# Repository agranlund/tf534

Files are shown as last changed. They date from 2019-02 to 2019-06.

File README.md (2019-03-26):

# Terriblefire TF534 

The TF534 doesnt work under 25Mhz. The firmware is designed to work between 25Mhz and 50Mhz. Its optimized for 50Mhz & 33Mhz.

Where this BOM differs from the schematic use the BOM value. 

| | | | | |
|---|---|---|---|---|
| "Part" | "Value" | "Device" | "Package" | "Description" |
| "C1" | "10uF" | "CAP_1206_X7R" | "1206" | "Ceramic Capacitors" |
| "C2" | "10uF" | "CAP_1206_X7R" | "1206" | "Ceramic Capacitors" |
| "C3" | "10uF" | "CAP_1206_X7R" | "1206" | "Ceramic Capacitors" |
| "C4" | "10uF" | "CAP_1206_X7R" | "1206" | "Ceramic Capacitors" |
| "C5" | "10uF" | "CAP_1206_X7R" | "1206" | "Ceramic Capacitors" |
| "C6" | "10uF" | "CAP_1206_X7R" | "1206" | "Ceramic Capacitors" |
| "C7" | "10uF" | "CAP_1206_X7R" | "1206" | "Ceramic Capacitors" |
| "C8" | "10uF" | "CAP_1206_X7R" | "1206" | "Ceramic Capacitors" |
| "C9" | "10uF" | "CAP_1206_X7R" | "1206" | "Ceramic Capacitors" |
| "C10" | "10uF" | "CAP_1206_X7R" | "1206" | "Ceramic Capacitors" |
| "C11" | "10uF" | "CAP_1206_X7R" | "1206" | "Ceramic Capacitors" |
| "C12" | "10uF" | "CAP_1206_X7R" | "1206" | "Ceramic Capacitors" |
| "C13" | "10uF" | "CAP_1206_X7R" | "1206" | "Ceramic Capacitors" |
| "C14" | "10uF" | "CAP_1206_X7R" | "1206" | "Ceramic Capacitors" |
| "C15" | "10uF" | "CAP_1206_X7R" | "1206" | "Ceramic Capacitors" |
| "C16" | "0.1uF" | "CAP_0603_X7R" | "0603" | "CAP-00810" |
| "C17" | "0.1uF" | "CAP_0603_X7R" | "0603" | "CAP-00810" |
| "C18" | "0.1uF" | "CAP_1206_X7R" | "1206" | "Ceramic Capacitors" |
| "C19" | "0.1uF" | "CAP_0603_X7R" | "0603" | |
| "C20" | "0.1uF" | "CAP_0603_X7R" | "0603" | "CAP-00810" |
| "C21" | "0.1uF" | "CAP_0603_X7R" | "0603" | |
| "C22" | "0.1uF" | "CAP_0603_X7R" | "0603" | |
| "C23" | "0.1uF" | "CAP_0603_X7R" | "0603" | |
| "C24" | "0.1uF" | "CAP_0603_X7R" | "0603" | |
| "C25" | "0.1uF" | "CAP_0603_X7R" | "0603" | |
| "C26" | "0.1uF" | "CAP_0603_X7R" | "0603" | |
| "C27" | "0.1uF" | "CAP_0603_X7R" | "0603" | |
| "C28" | "0.1uF" | "CAP_0603_X7R" | "0603" | |
| "C29" | "0.1uF" | "CAP_0603_X7R" | "0603" | |
| "C30" | "0.1uF" | "CAP_0603_X7R" | "0603" | |
| "C31" | "10uF" | "CAP_1206_X7R" | "1206" | "Ceramic Capacitors" |
| "IC1" | "MC68030RC" | "68030" | "MPGA128" | "MOTOROLA" |
| "IC2" | "MC68881FN-SOC" | "68882" | "PLCC68-S" | "unknown" |
| "IC3" | "LM1117-3.3" | "V_REG_LM1117SOT223" | "SOT223" | "Voltage Regulator LM1117" |
| "IC4" | "74LVC1G17DBV" | "74LVC1G17DBV" | "SOT23-5" | "Single Schmitt-Trigger Buffer" |
| "IC5" | "74LVC1G17DBV" | "74LVC1G17DBV" | "SOT23-5" | "Single Schmitt-Trigger Buffer" |
| "IC6" | "AS6C800855ZIN" | "AS6C800855ZIN" | "TSOP44-II" | |
| "IC7" | "AS6C800855ZIN" | "AS6C800855ZIN" | "TSOP44-II" | |
| "IC8" | "AS6C800855ZIN" | "AS6C800855ZIN" | "TSOP44-II" | |
| "IC9" | "AS6C800855ZIN" | "AS6C800855ZIN" | "TSOP44-II" | |
| "IC10" | "74AC16245" | "74AC16245" | "SSOP48DL" | "16-bit BUS TRANSCEIVER, 3-state" |
| "IDECONNECTOR" | "87758-4416" | "87758-4416" | "87758-4416" | "44 Pin - 2mm Dual Row  HDR" |
| "INT2" | "PINHD-1X1" | "1X01" | "PIN HEADER" | |
| "JP1" | "CLOCKSEL" | "JUMPER-3PTH" | "1X03" | |
| "JP2" | "Z2ROM" | "JUMPER-2PTH" | "1X02" | "Jumper" |
| "JP3" | "MMUDIS" | "JUMPER-2PTH" | "1X02" | "Jumper" |
| "JP4" | "ROMEN" | "JUMPER-2PTH" | "1X02" | "Jumper" |
| "JP5" | "CDIS" | "JUMPER-2PTH" | "1X02" | "Jumper" |
| "JTAG" | "JTAG" | "HEADER-1X6" | "0.1 header x 6" | "PIN HEADER" |
| "OSCCPU" | "CPUMHZ" | "OSCILLATOR" | "OSC_7X5MM" | "Oscillators" |
| "PWR1" | "EXT5V" | "JUMPER-2PTH" | "1X02" | "Jumper" |
| "R1" | "2K2" | "0.05OHM-1/5W-1%(0603)" | "0603" | "RES-12535" |
| "R2" | "2K2" | "0.05OHM-1/5W-1%(0603)" | "0603" | "RES-12535" |
| "R3" | "47K" | "RESISTOR1206" | "1206" | "Resistors" |
| "RN1" | "CAY16-222J4LF" | "CAY16-222J4LF" | "RESCAXE80P320X160-8N" | "Res Thick Film Array 2K2 Ohm" |
| "RN2" | "CAY16-222J4LF" | "CAY16-222J4LF" | "RESCAXE80P320X160-8N" | "Res Thick Film Array 2K2 Ohm" |
| "RN3" | "CAY16-222J4LF" | "CAY16-222J4LF" | "RESCAXE80P320X160-8N" | "Res Thick Film Array 2K2 Ohm" |
| "SPIPORT" | "SPI PORT" | "PINHD-2X6" | "2X06" | "PIN HEADER" |
| "SPI_INT" | "NONE" | "PINHD-1X1" | "1X01" | "PIN HEADER" |
| "U1" | "3.3V SPI Flash"  | "SST26VF016B" | "SO08" | "32M Serial Flash Memory" |
| "X1" | "MC68000" | "MC68000P" | "DIL64" | "68xxx PROCESSOR" |
| "XC9572XL(BUS)"  | "XC9572XL-VQ64" | "XC9572XL-VQ64" | "VQ64" | |
| "XC95144XL(RAM)" | "XC95144XL-TQ100" | "XC95144XL-TQ100" | "TQFP100" | |

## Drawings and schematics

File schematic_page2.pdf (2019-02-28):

# 19 D0

# 36 GND

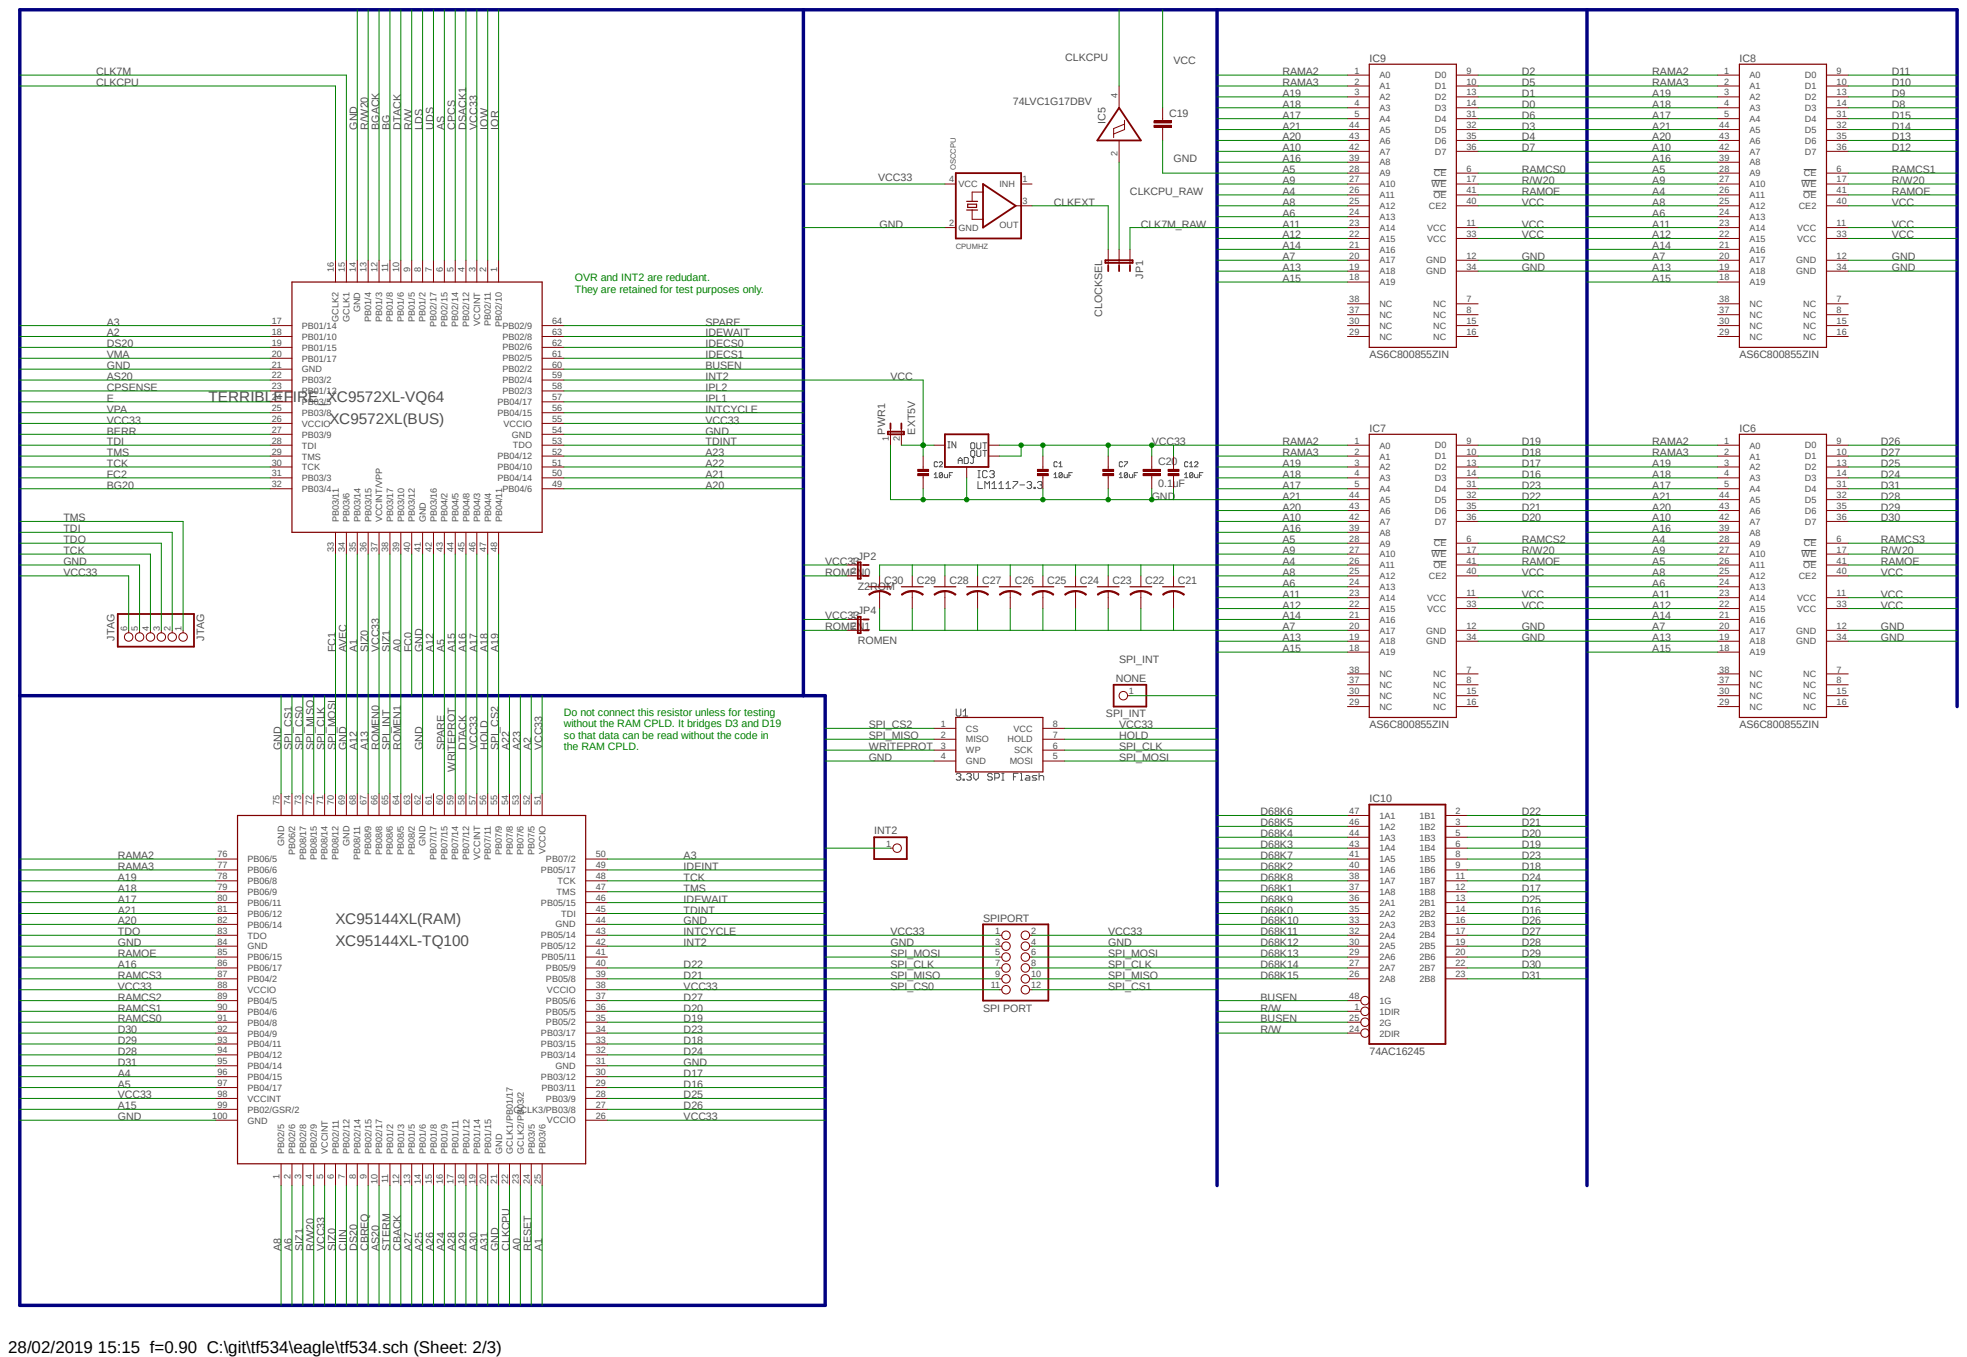
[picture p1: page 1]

A18 | | A18 | 14 D4 D8
A17 | D6 | A17 | 31 D5
A21 | | A21 44 A6 | 32 D6
A20 | | A20 43 A7 | 35 D7
A10 | | A10 42 A8

A6 | VCC | A6 | 40 VCC 11 VCC VCC
A8 | VCC | A8 | VCC

7 PB03/2 22 PB03/3 31 PB03/4 32 PB03/5 24 PB03/6 34 PB03/8 25 PB03/9 27 PB03/10 39 PB03/11 33 PB03/12 40 PB03/14 35 PB03/15 36 PB03/16 42 PB03/17 38 PB04/2 43 PB04/3 46 PB04/4 47 PB04/5 44 PB04/6 49 PB04/8 45 PB04/10 51 PB04/11 48 PB04/12 52 PB04/14 50 PB04/15 56 PB04/17 57 TCK 30 TDI 28 TDO 53 TMS 29 VCCINT

3 VCCINT/VPP 37 VCCIO 55 VCCIO 26 XC9572XL(BUS)

A15 | | A15 | 34 NC 7 NC 8 NC 15 NC
A13 | GND | A13 | GND

OVR and INT2 are redudant.
They are retained for test purposes only.

IDECS1 | AS6C800855ZIN IC7 | AS6C800855ZIN

GND | BUSEN
AS20 | INT2
CPSENSE | IPL2 | JP2 1

A11 | VCC | A11 A8 | 40 VCC 11 VCC VCC

VCC | | 33 VCC

GND | | 12 GND GND

Do not connect this resistor unless for testing
without the RAM CPLD. It bridges D3 and D19
so that data can be read without the code in
the RAM CPLD.

6 VCCIO 26 GND 31 PB05/2 35 PB05/5 36 PB05/6 37 PB05/8 39 PB05/9 40 PB05/11 41 PB05/12 42 PB05/14 43 PB05/15 46 PB05/17 49 VCCIO 38 GND 44 PB07/2 PB07/5 50 52 PB07/6 53 PB08/2 63 PB07/8 54 PB07/9 55 PB07/11 56 PB07/12 58 PB07/14 59 PB07/15 60 PB07/17 61 VCCIO 51 VCCINT 57 PB08/5 64 PB08/6 65 PB08/8 66 PB08/9 67 PB08/11 68 PB08/12 70 PB08/14 71 PB08/15 72 PB08/17 73 GND 69 PB06/2 74 PB06/5 76 PB06/6 77 PB06/8 78 PB06/9 79 PB06/11 80 PB06/12 81 PB06/14 82 PB06/15 85 PB06/17 86 GND 75 GND 84 PB04/2 87 PB04/5 89 PB04/6 90 PB04/8 91 PB04/9 92 PB04/11 93 PB04/12 94 PB04/14 95 PB04/15 96 PB04/17 97 VCCIO 88 GND 100 VCCINT 98 PB02/GSR/2 99

VCC33 | VCC33
RAMCS2 | D27
RAMCS0 | D19
D30 | D23
D29 | D18
D28 | D24
D31 | GND
A5 | D16
VCC33 | D25

28/02/2019 15:15 f=0.90 C:\git\tf534\eagle\tf534.sch (Sheet: 2/3)

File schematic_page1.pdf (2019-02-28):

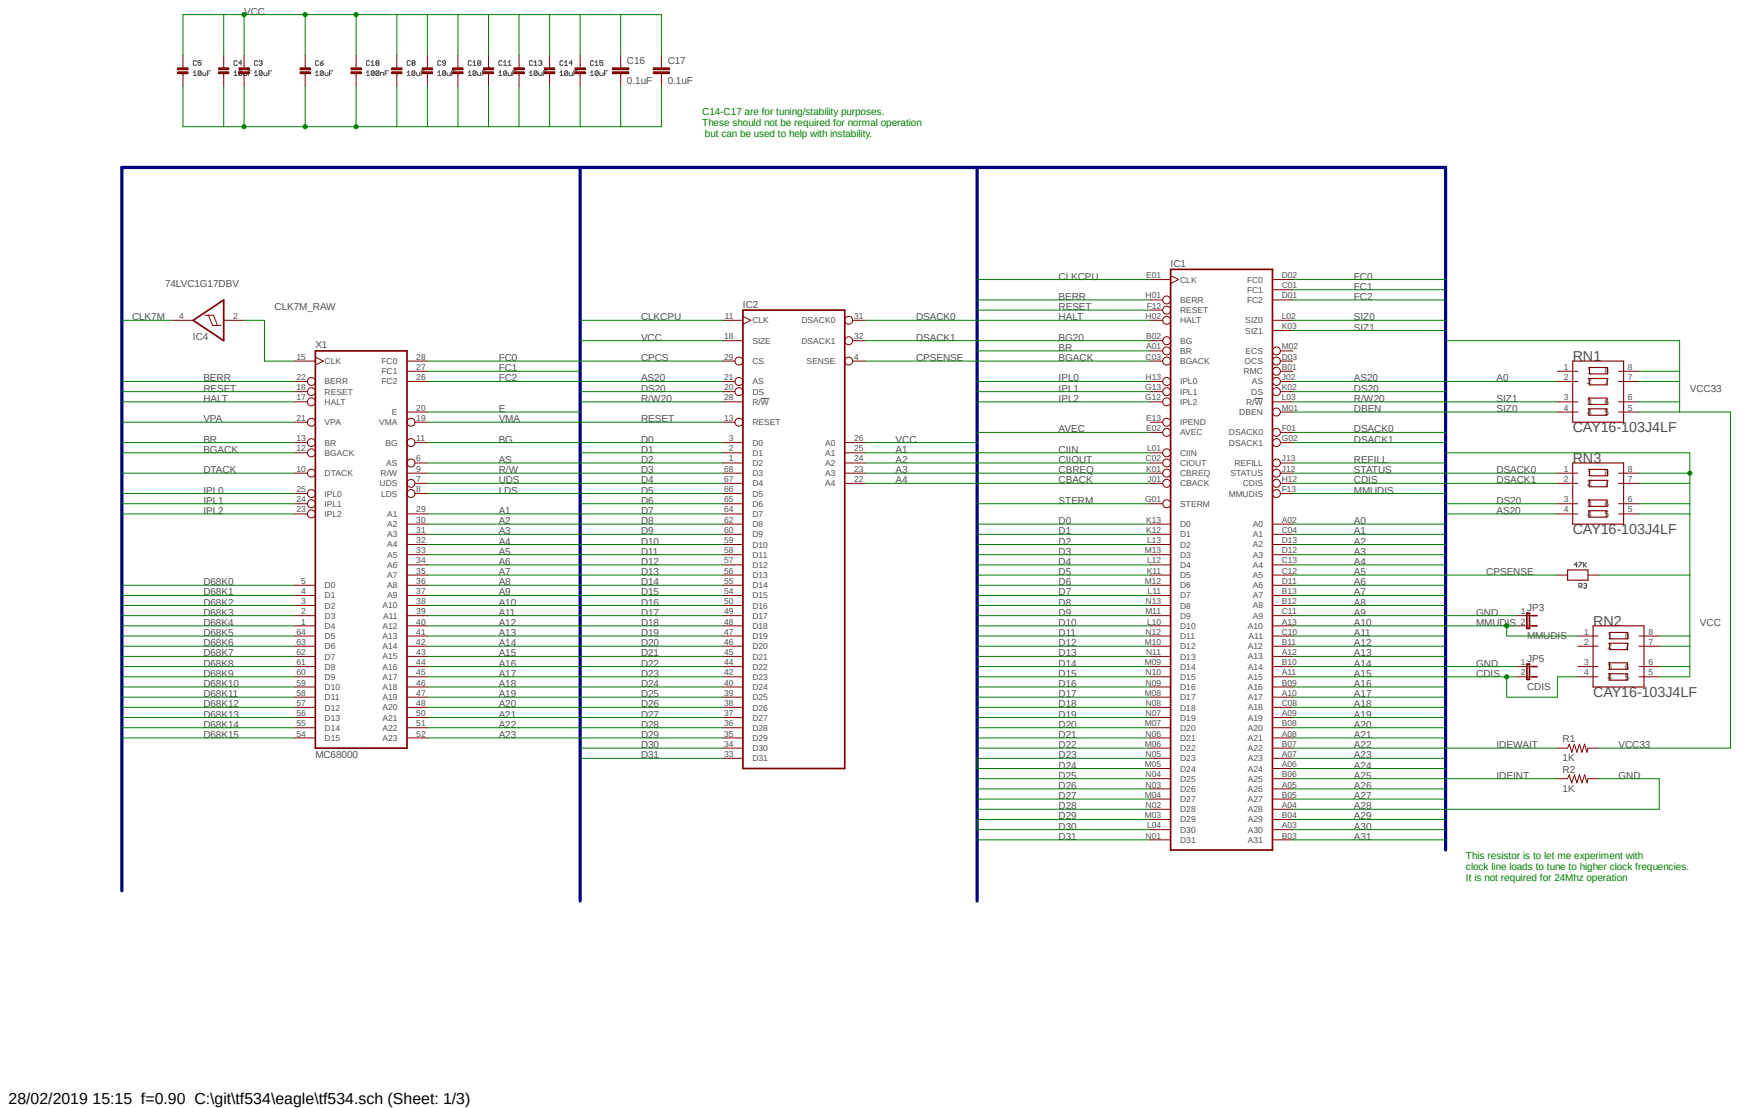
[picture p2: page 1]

C14-C17 are for tuning/stability purposes.
These should not be required for normal operation
but can be used to help with instability.

D68K1 | A9
D68K2 | | D16

D24 | A24
D25 | A25
D26 | A26 | 1K
D27 | A27
D28 | A28
D29 | A29
D30 | A30
D31 | A31

This resistor is to let me experiment with
clock line loads to tune to higher clock frequencies.
It is not required for 24Mhz operation

28/02/2019 15:15 f=0.90 C:\git\tf534\eagle\tf534.sch (Sheet: 1/3)

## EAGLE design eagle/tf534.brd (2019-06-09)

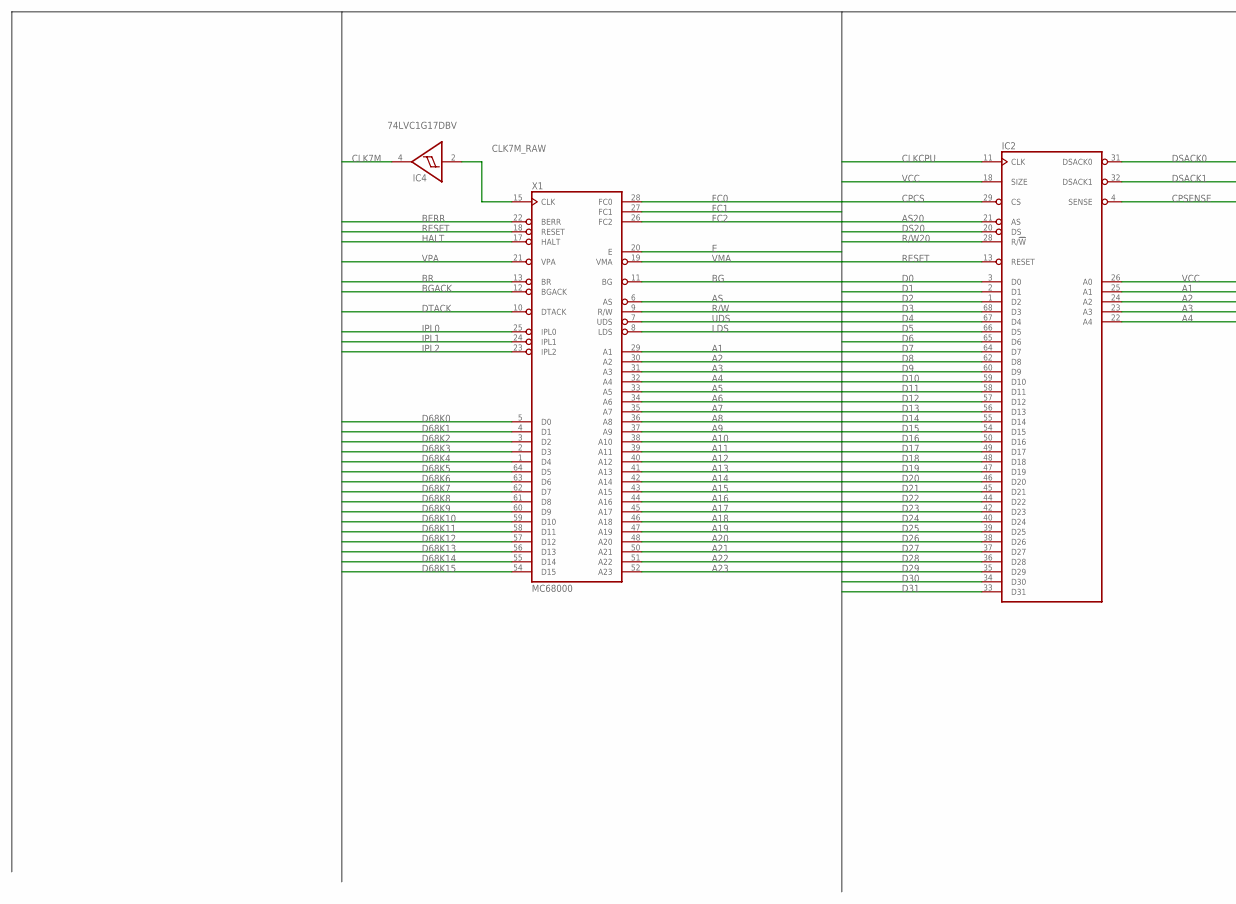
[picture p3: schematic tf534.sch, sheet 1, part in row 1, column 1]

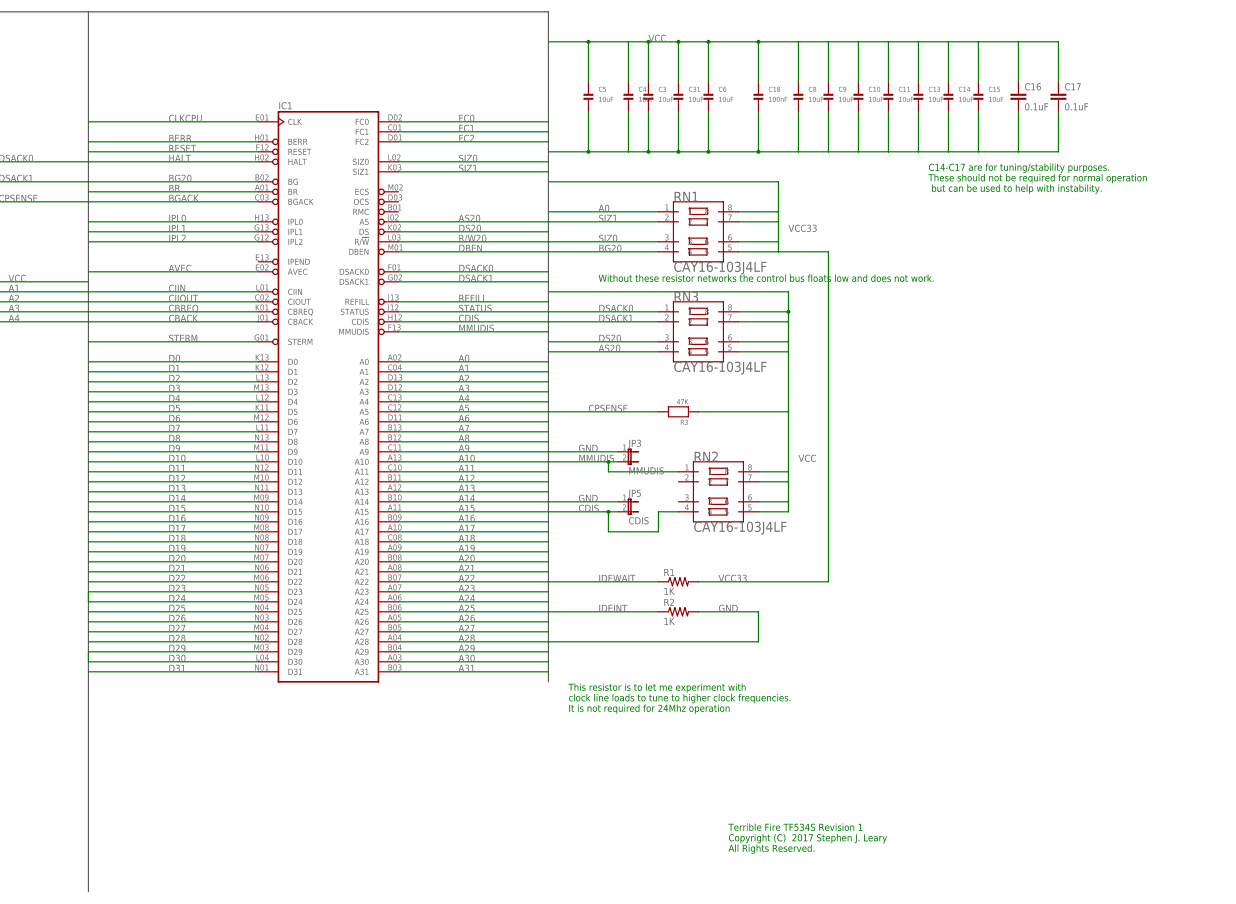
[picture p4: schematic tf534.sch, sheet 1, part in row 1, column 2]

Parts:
C3, C4, C5, C6, C8, C9, C10, C11, C13, C14, C15, C31: 10uF; 1206
C16, C17: 0.1uF; 0603-CAP
C18: 100nF; 1206
IC1: MC68030RC; MPGA128
IC2: MC68881FN-SOC; PLCC68-S
IC4: 74LVC1G17DBV; SOT23-5
JP3: MMUDIS; 1X02
JP5: CDIS; 1X02
R1, R2: 1K; 0603
R3: 47K; 1206
RN1, RN2, RN3: CAY16-103J4LF; RESCAXE80P320X160-8N
X1: MC68000; DIL64

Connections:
A0: IC1.A02 (A0), RN1.1; also elsewhere on the board
A1: IC1.C04 (A1), IC2.25 (A1), X1.29 (A1); also elsewhere on the board
A2: IC1.D13 (A2), IC2.24 (A2), X1.30 (A2); also elsewhere on the board
A3: IC1.D12 (A3), IC2.23 (A3), X1.31 (A3); also elsewhere on the board
A4: IC1.C13 (A4), IC2.22 (A4), X1.32 (A4); also elsewhere on the board
A5: IC1.C12 (A5), X1.33 (A5); also elsewhere on the board
A6: IC1.D11 (A6), X1.34 (A6); also elsewhere on the board
A7: IC1.B13 (A7), X1.35 (A7); also elsewhere on the board
A8: IC1.B12 (A8), X1.36 (A8); also elsewhere on the board
A9: IC1.C11 (A9), X1.37 (A9); also elsewhere on the board
A10: IC1.A13 (A10), X1.38 (A10); also elsewhere on the board
A11: IC1.C10 (A11), X1.39 (A11); also elsewhere on the board
A12: IC1.B11 (A12), X1.40 (A12); also elsewhere on the board
A13: IC1.A12 (A13), X1.41 (A13); also elsewhere on the board
A14: IC1.B10 (A14), X1.42 (A14); also elsewhere on the board
A15: IC1.A11 (A15), X1.43 (A15); also elsewhere on the board
A16: IC1.B09 (A16), X1.44 (A16); also elsewhere on the board
A17: IC1.A10 (A17), X1.45 (A17); also elsewhere on the board
A18: IC1.C08 (A18), X1.46 (A18); also elsewhere on the board
A19: IC1.A09 (A19), X1.47 (A19); also elsewhere on the board
A20: IC1.B08 (A20), X1.48 (A20); also elsewhere on the board
A21: IC1.A08 (A21), X1.50 (A21); also elsewhere on the board
A22: IC1.B07 (A22), X1.51 (A22); also elsewhere on the board
A23: IC1.A07 (A23), X1.52 (A23); also elsewhere on the board
A24: IC1.A06 (A24); also elsewhere on the board
A25: IC1.B06 (A25); also elsewhere on the board
A26: IC1.A05 (A26); also elsewhere on the board
A27: IC1.B05 (A27); also elsewhere on the board
A28: IC1.A04 (A28); also elsewhere on the board
A29: IC1.B04 (A29); also elsewhere on the board
A30: IC1.A03 (A30); also elsewhere on the board
A31: IC1.B03 (A31); also elsewhere on the board
AS: X1.6 (AS); also elsewhere on the board
AS20: IC1.J02 (AS), IC2.21 (AS), RN3.4; also elsewhere on the board
AVEC: IC1.E02 (AVEC); also elsewhere on the board
BERR: IC1.H01 (BERR), X1.22 (BERR); also elsewhere on the board
BG: X1.11 (BG); also elsewhere on the board
BG20: IC1.B02 (BG), RN1.4; also elsewhere on the board
BGACK: IC1.C03 (BGACK), X1.12 (BGACK); also elsewhere on the board
BR: IC1.A01 (BR), X1.13 (BR)
CBACK: IC1.J01 (CBACK); also elsewhere on the board
CBREQ: IC1.K01 (CBREQ); also elsewhere on the board
CDIS: IC1.H12 (CDIS), JP5.2, RN2.4
CIIN: IC1.L01 (CIIN); also elsewhere on the board
CIIOUT: IC1.C02 (CIOUT)
CLK7M: IC4.4 (O); also elsewhere on the board
CLK7M_RAW: IC4.2 (I), X1.15 (CLK); also elsewhere on the board
CLKCPU: IC1.E01 (CLK), IC2.11 (CLK); also elsewhere on the board
CPCS: IC2.29 (CS); also elsewhere on the board
CPSENSE: IC2.4 (SENSE), R3.2; also elsewhere on the board
D0: IC1.K13 (D0), IC2.3 (D0); also elsewhere on the board
D1: IC1.K12 (D1), IC2.2 (D1); also elsewhere on the board
D2: IC1.L13 (D2), IC2.1 (D2); also elsewhere on the board
D3: IC1.M13 (D3), IC2.68 (D3); also elsewhere on the board
D4: IC1.L12 (D4), IC2.67 (D4); also elsewhere on the board
D5: IC1.K11 (D5), IC2.66 (D5); also elsewhere on the board
D6: IC1.M12 (D6), IC2.65 (D6); also elsewhere on the board
D7: IC1.L11 (D7), IC2.64 (D7); also elsewhere on the board
D8: IC1.N13 (D8), IC2.62 (D8); also elsewhere on the board
D9: IC1.M11 (D9), IC2.60 (D9); also elsewhere on the board
D10: IC1.L10 (D10), IC2.59 (D10); also elsewhere on the board
D11: IC1.N12 (D11), IC2.58 (D11); also elsewhere on the board
D12: IC1.M10 (D12), IC2.57 (D12); also elsewhere on the board
D13: IC1.N11 (D13), IC2.56 (D13); also elsewhere on the board
D14: IC1.M09 (D14), IC2.55 (D14); also elsewhere on the board
D15: IC1.N10 (D15), IC2.54 (D15); also elsewhere on the board
D16: IC1.N09 (D16), IC2.50 (D16); also elsewhere on the board
D17: IC1.M08 (D17), IC2.49 (D17); also elsewhere on the board
D18: IC1.N08 (D18), IC2.48 (D18); also elsewhere on the board
D19: IC1.N07 (D19), IC2.47 (D19); also elsewhere on the board
D20: IC1.M07 (D20), IC2.46 (D20); also elsewhere on the board
D21: IC1.N06 (D21), IC2.45 (D21); also elsewhere on the board
D22: IC1.M06 (D22), IC2.44 (D22); also elsewhere on the board
D23: IC1.N05 (D23), IC2.42 (D23); also elsewhere on the board
D24: IC1.M05 (D24), IC2.40 (D24); also elsewhere on the board
D25: IC1.N04 (D25), IC2.39 (D25); also elsewhere on the board
D26: IC1.N03 (D26), IC2.38 (D26); also elsewhere on the board
D27: IC1.M04 (D27), IC2.37 (D27); also elsewhere on the board
D28: IC1.N02 (D28), IC2.36 (D28); also elsewhere on the board
D29: IC1.M03 (D29), IC2.35 (D29); also elsewhere on the board
D30: IC1.L04 (D30), IC2.34 (D30); also elsewhere on the board
D31: IC1.N01 (D31), IC2.33 (D31); also elsewhere on the board
D68K0: X1.5 (D0); also elsewhere on the board
D68K1: X1.4 (D1); also elsewhere on the board
D68K2: X1.3 (D2); also elsewhere on the board
D68K3: X1.2 (D3); also elsewhere on the board
D68K4: X1.1 (D4); also elsewhere on the board
D68K5: X1.64 (D5); also elsewhere on the board
D68K6: X1.63 (D6); also elsewhere on the board
D68K7: X1.62 (D7); also elsewhere on the board
D68K8: X1.61 (D8); also elsewhere on the board
D68K9: X1.60 (D9); also elsewhere on the board
D68K10: X1.59 (D10); also elsewhere on the board
D68K11: X1.58 (D11); also elsewhere on the board
D68K12: X1.57 (D12); also elsewhere on the board
D68K13: X1.56 (D13); also elsewhere on the board
D68K14: X1.55 (D14); also elsewhere on the board
D68K15: X1.54 (D15); also elsewhere on the board
DBEN: IC1.M01 (DBEN)
DS20: IC1.K02 (DS), IC2.20 (DS), RN3.3; also elsewhere on the board
DSACK0: IC1.F01 (DSACK0), IC2.31 (DSACK0), RN3.1
DSACK1: IC1.G02 (DSACK1), IC2.32 (DSACK1), RN3.2; also elsewhere on the board
DTACK: X1.10 (DTACK); also elsewhere on the board
E: X1.20 (E); also elsewhere on the board
FC0: IC1.D02 (FC0), X1.28 (FC0); also elsewhere on the board
FC1: IC1.C01 (FC1), X1.27 (FC1); also elsewhere on the board
FC2: IC1.D01 (FC2), X1.26 (FC2); also elsewhere on the board
GND: C3.2, C4.2, C5.2, C6.2, C8.2, C9.2, C10.2, C11.2, C13.2, C14.2, C15.2, C16.2, C17.2, C18.2, C31.2, IC1.C05 (GND), IC1.C07 (GND), IC1.C09 (GND), IC1.E03 (GND), IC1.E11 (GND), IC1.F03 (GND), IC1.G03 (GND), IC1.G11 (GND), IC1.J03 (GND), IC1.J11 (GND), IC1.L05 (GND), IC1.L07 (GND), IC1.L08 (GND), IC1.L09 (GND), IC2.5 (GND), IC2.6 (GND), IC2.7 (GND), IC2.8 (GND), IC2.9 (GND), IC2.12 (GND), IC2.14 (GND), IC2.19 (GND), IC2.30 (GND), IC2.41 (GND), IC2.51 (GND), IC2.63 (GND), IC4.3 (GND), JP3.1, JP5.1, R2.2, X1.16 (GND), X1.53 (GND); also elsewhere on the board
HALT: IC1.H02 (HALT), X1.17 (HALT)
IDEINT: R2.1; also elsewhere on the board
IDEWAIT: R1.1; also elsewhere on the board
IPL0: IC1.H13 (IPL0), X1.25 (IPL0)
IPL1: IC1.G13 (IPL1), X1.24 (IPL1); also elsewhere on the board
IPL2: IC1.G12 (IPL2), X1.23 (IPL2); also elsewhere on the board
LDS: X1.8 (LDS); also elsewhere on the board
MMUDIS: IC1.F13 (MMUDIS), JP3.2, RN2.1
R/W: X1.9 (R/W); also elsewhere on the board
R/W20: IC1.L03 (R/!W), IC2.28 (R/!W); also elsewhere on the board
REFILL: IC1.J13 (REFILL)
RESET: IC1.F12 (RESET), IC2.13 (RESET), X1.18 (RESET); also elsewhere on the board
SIZ0: IC1.L02 (SIZ0), RN1.3; also elsewhere on the board
SIZ1: IC1.K03 (SIZ1), RN1.2; also elsewhere on the board
STATUS: IC1.J12 (STATUS)
STERM: IC1.G01 (STERM); also elsewhere on the board
UDS: X1.7 (UDS); also elsewhere on the board
VCC: C3.1, C4.1, C5.1, C6.1, C8.1, C9.1, C10.1, C11.1, C13.1, C14.1, C15.1, C16.1, C17.1, C18.1, C31.1, IC1.C06 (VCC), IC1.D04 (VCC), IC1.D10 (VCC), IC1.F02 (VCC), IC1.F11 (VCC), IC1.H03 (VCC), IC1.H11 (VCC), IC1.K04 (VCC), IC1.K10 (VCC), IC1.L06 (VCC), IC2.10 (VCC), IC2.16 (VCC), IC2.17 (VCC), IC2.18 (SIZE), IC2.26 (A0), IC2.27 (VCC), IC2.43 (VCC), IC2.52 (VCC), IC2.53 (VCC), IC2.61 (VCC), IC4.5 (VCC), R3.1, RN2.5, RN2.6, RN2.7, RN2.8, RN3.5, RN3.6, RN3.7, RN3.8, X1.14 (VCC), X1.49 (VCC); also elsewhere on the board
VCC33: R1.2, RN1.5, RN1.6, RN1.7, RN1.8; also elsewhere on the board
VMA: X1.19 (VMA); also elsewhere on the board
VPA: X1.21 (VPA); also elsewhere on the board

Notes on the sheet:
This resistor is to let me experiment with clock line loads to tune to higher clock frequencies. It is not required for 24Mhz operation
C14-C17 are for tuning/stability purposes. These should not be required for normal operation but can be used to help with instability.
Without these resistor networks the control bus floats low and does not work.
Terrible Fire TF534S Revision 1 Copyright (C) 2017 Stephen J. Leary All Rights Reserved.

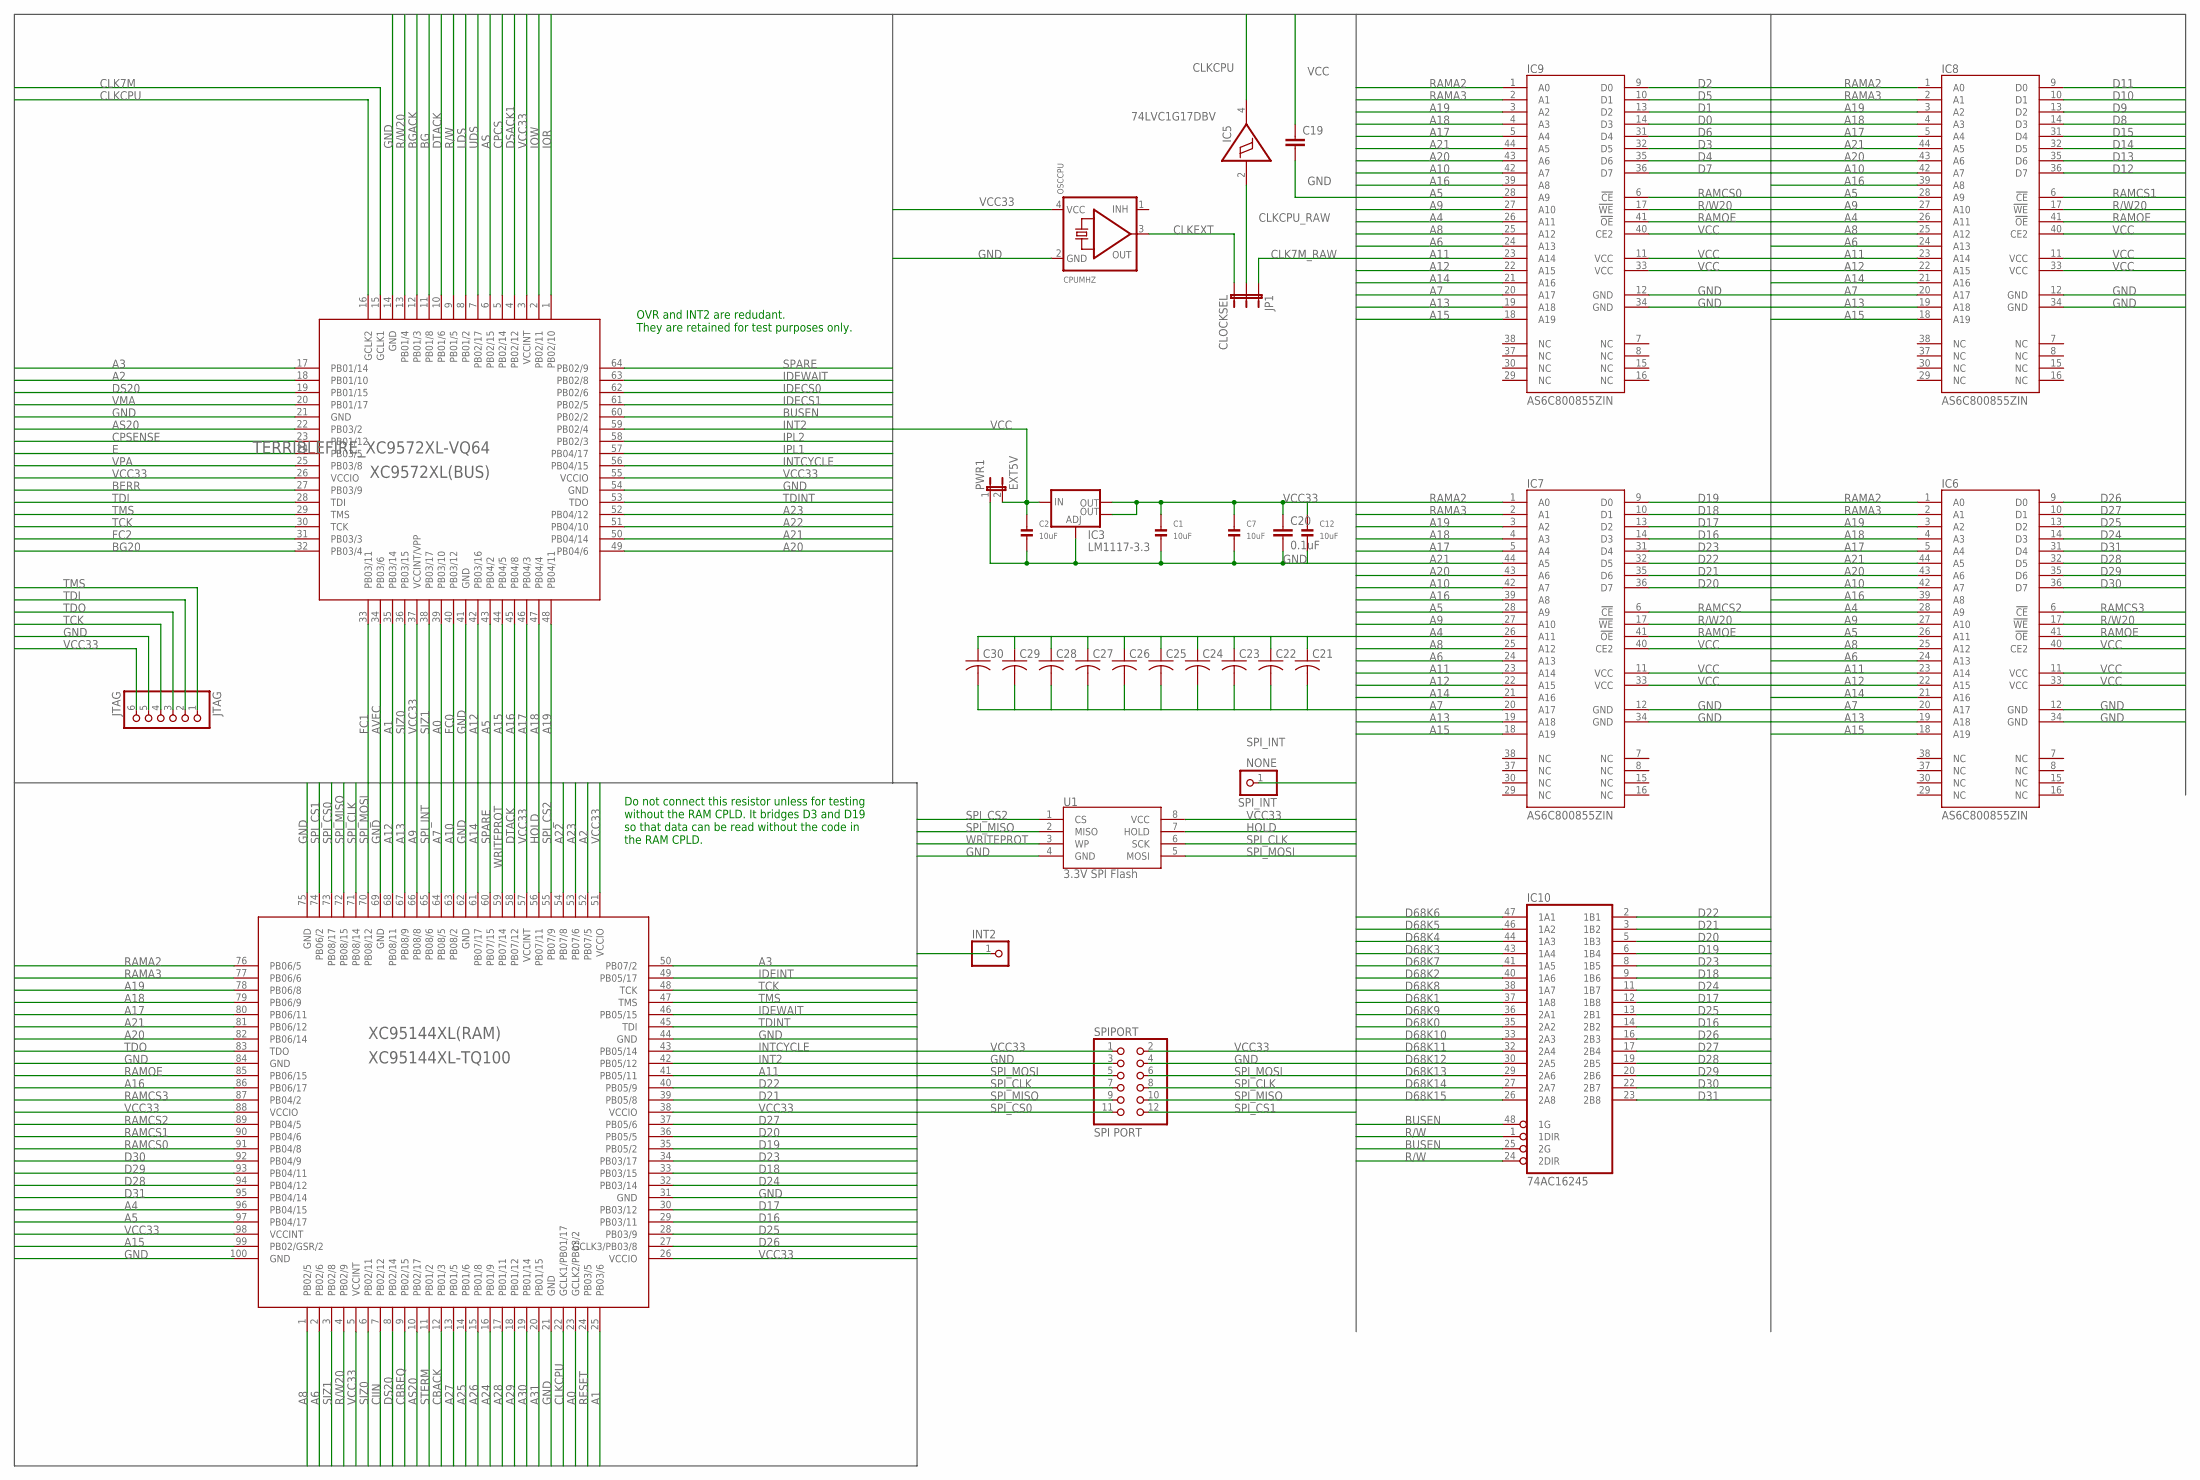
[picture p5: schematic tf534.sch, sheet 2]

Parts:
C1, C2, C7, C12: 10uF; 1206
C19: CC0603; C0603
C20: 0.1uF; 0603-CAP
C21, C22, C23, C24, C25, C26, C27, C28, C29, C30: C-USC0603; C0603
IC3: LM1117-3.3; SOT223
IC5: 74LVC1G17DBV; SOT23-5
IC6, IC7, IC8, IC9: AS6C800855ZIN; TSOP44-II
IC10: 74AC16245; SSOP48DL
INT2: PINHD-1X1; 1X01
JP1: CLOCKSEL; 1X03
JTAG: JTAG; 1X06_ROUND
OSCCPU: CPUMHZ; OSC_7X5MM
PWR1: EXT5V; 1X02
SPIPORT: SPI PORT; 2X06
SPI_INT: NONE; 1X01
U1: 3.3V SPI Flash; SO08
XC9572XL(BUS): TERRIBLEFIRE_XC9572XL-VQ64; TERRIBLEFIRE_VQ64
XC95144XL(RAM): XC95144XL-TQ100; TQFP100

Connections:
A0: XC9572XL(BUS).39 (PB03/10), XC95144XL(RAM).23 (GCLK2/PB03/2); also elsewhere on the board
A1: XC9572XL(BUS).35 (PB03/14), XC95144XL(RAM).25 (PB03/6); also elsewhere on the board
A2: XC9572XL(BUS).18 (PB01/10), XC95144XL(RAM).52 (PB07/5); also elsewhere on the board
A3: XC9572XL(BUS).17 (PB01/14), XC95144XL(RAM).50 (PB07/2); also elsewhere on the board
A4: IC6.28 (A9), IC7.26 (A11), IC8.26 (A11), IC9.26 (A11), XC95144XL(RAM).96 (PB04/15); also elsewhere on the board
A5: IC6.26 (A11), IC7.28 (A9), IC8.28 (A9), IC9.28 (A9), XC9572XL(BUS).43 (PB04/2), XC95144XL(RAM).97 (PB04/17); also elsewhere on the board
A6: IC6.24 (A13), IC7.24 (A13), IC8.24 (A13), IC9.24 (A13), XC95144XL(RAM).2 (PB02/6); also elsewhere on the board
A7: IC6.20 (A17), IC7.20 (A17), IC8.20 (A17), IC9.20 (A17), XC95144XL(RAM).64 (PB08/5); also elsewhere on the board
A8: IC6.25 (A12), IC7.25 (A12), IC8.25 (A12), IC9.25 (A12), XC95144XL(RAM).1 (PB02/5); also elsewhere on the board
A9: IC6.27 (A10), IC7.27 (A10), IC8.27 (A10), IC9.27 (A10), XC95144XL(RAM).66 (PB08/8); also elsewhere on the board
A10: IC6.42 (A7), IC7.42 (A7), IC8.42 (A7), IC9.42 (A7), XC95144XL(RAM).63 (PB08/2); also elsewhere on the board
A11: IC6.23 (A14), IC7.23 (A14), IC8.23 (A14), IC9.23 (A14), XC95144XL(RAM).41 (PB05/11); also elsewhere on the board
A12: IC6.22 (A15), IC7.22 (A15), IC8.22 (A15), IC9.22 (A15), XC9572XL(BUS).42 (PB03/16), XC95144XL(RAM).68 (PB08/11); also elsewhere on the board
A13: IC6.19 (A18), IC7.19 (A18), IC8.19 (A18), IC9.19 (A18), XC95144XL(RAM).67 (PB08/9); also elsewhere on the board
A14: IC6.21 (A16), IC7.21 (A16), IC8.21 (A16), IC9.21 (A16), XC95144XL(RAM).61 (PB07/17); also elsewhere on the board
A15: IC6.18 (A19), IC7.18 (A19), IC8.18 (A19), IC9.18 (A19), XC9572XL(BUS).44 (PB04/5), XC95144XL(RAM).99 (PB02/GSR/2); also elsewhere on the board
A16: IC6.39 (A8), IC7.39 (A8), IC8.39 (A8), IC9.39 (A8), XC9572XL(BUS).45 (PB04/8), XC95144XL(RAM).86 (PB06/17); also elsewhere on the board
A17: IC6.5 (A4), IC7.5 (A4), IC8.5 (A4), IC9.5 (A4), XC9572XL(BUS).46 (PB04/3), XC95144XL(RAM).80 (PB06/11); also elsewhere on the board
A18: IC6.4 (A3), IC7.4 (A3), IC8.4 (A3), IC9.4 (A3), XC9572XL(BUS).47 (PB04/4), XC95144XL(RAM).79 (PB06/9); also elsewhere on the board
A19: IC6.3 (A2), IC7.3 (A2), IC8.3 (A2), IC9.3 (A2), XC9572XL(BUS).48 (PB04/11), XC95144XL(RAM).78 (PB06/8); also elsewhere on the board
A20: IC6.43 (A6), IC7.43 (A6), IC8.43 (A6), IC9.43 (A6), XC9572XL(BUS).49 (PB04/6), XC95144XL(RAM).82 (PB06/14); also elsewhere on the board
A21: IC6.44 (A5), IC7.44 (A5), IC8.44 (A5), IC9.44 (A5), XC9572XL(BUS).50 (PB04/14), XC95144XL(RAM).81 (PB06/12); also elsewhere on the board
A22: XC9572XL(BUS).51 (PB04/10), XC95144XL(RAM).54 (PB07/8); also elsewhere on the board
A23: XC9572XL(BUS).52 (PB04/12), XC95144XL(RAM).53 (PB07/6); also elsewhere on the board
A24: XC95144XL(RAM).16 (PB01/9); also elsewhere on the board
A25: XC95144XL(RAM).14 (PB01/6); also elsewhere on the board
A26: XC95144XL(RAM).15 (PB01/8); also elsewhere on the board
A27: XC95144XL(RAM).13 (PB01/5); also elsewhere on the board
A28: XC95144XL(RAM).17 (PB01/11); also elsewhere on the board
A29: XC95144XL(RAM).18 (PB01/12); also elsewhere on the board
A30: XC95144XL(RAM).19 (PB01/14); also elsewhere on the board
A31: XC95144XL(RAM).20 (PB01/15); also elsewhere on the board
AS: XC9572XL(BUS).6 (PB02/15); also elsewhere on the board
AS20: XC9572XL(BUS).22 (PB03/2), XC95144XL(RAM).10 (PB02/17); also elsewhere on the board
AVEC: XC9572XL(BUS).34 (PB03/6); also elsewhere on the board
BERR: XC9572XL(BUS).27 (PB03/9); also elsewhere on the board
BG: XC9572XL(BUS).11 (PB01/8); also elsewhere on the board
BG20: XC9572XL(BUS).32 (PB03/4); also elsewhere on the board
BGACK: XC9572XL(BUS).12 (PB01/3); also elsewhere on the board
BUSEN: IC10.25 (2G), IC10.48 (1G), XC9572XL(BUS).60 (PB02/2)
CBACK: XC95144XL(RAM).12 (PB01/3); also elsewhere on the board
CBREQ: XC95144XL(RAM).9 (PB02/15); also elsewhere on the board
CIIN: XC95144XL(RAM).7 (PB02/12); also elsewhere on the board
CLK7M: XC9572XL(BUS).15 (GCLK1); also elsewhere on the board
CLK7M_RAW: JP1.1; also elsewhere on the board
CLKCPU: IC5.4 (O), XC9572XL(BUS).16 (GCLK2), XC95144XL(RAM).22 (GCLK1/PB01/17); also elsewhere on the board
CLKCPU_RAW: IC5.2 (I), JP1.2
CLKEXT: JP1.3, OSCCPU.3 (OUT)
CPCS: XC9572XL(BUS).5 (PB02/14); also elsewhere on the board
CPSENSE: XC9572XL(BUS).23 (PB01/12); also elsewhere on the board
D0: IC9.14 (D3); also elsewhere on the board
D1: IC9.13 (D2); also elsewhere on the board
D2: IC9.9 (D0); also elsewhere on the board
D3: IC9.32 (D5); also elsewhere on the board
D4: IC9.35 (D6); also elsewhere on the board
D5: IC9.10 (D1); also elsewhere on the board
D6: IC9.31 (D4); also elsewhere on the board
D7: IC9.36 (D7); also elsewhere on the board
D8: IC8.14 (D3); also elsewhere on the board
D9: IC8.13 (D2); also elsewhere on the board
D10: IC8.10 (D1); also elsewhere on the board
D11: IC8.9 (D0); also elsewhere on the board
D12: IC8.36 (D7); also elsewhere on the board
D13: IC8.35 (D6); also elsewhere on the board
D14: IC8.32 (D5); also elsewhere on the board
D15: IC8.31 (D4); also elsewhere on the board
D16: IC7.14 (D3), IC10.14 (2B2), XC95144XL(RAM).29 (PB03/11); also elsewhere on the board
D17: IC7.13 (D2), IC10.12 (1B8), XC95144XL(RAM).30 (PB03/12); also elsewhere on the board
D18: IC7.10 (D1), IC10.9 (1B6), XC95144XL(RAM).33 (PB03/15); also elsewhere on the board
D19: IC7.9 (D0), IC10.6 (1B4), XC95144XL(RAM).35 (PB05/2); also elsewhere on the board
D20: IC7.36 (D7), IC10.5 (1B3), XC95144XL(RAM).36 (PB05/5); also elsewhere on the board
D21: IC7.35 (D6), IC10.3 (1B2), XC95144XL(RAM).39 (PB05/8); also elsewhere on the board
D22: IC7.32 (D5), IC10.2 (1B1), XC95144XL(RAM).40 (PB05/9); also elsewhere on the board
D23: IC7.31 (D4), IC10.8 (1B5), XC95144XL(RAM).34 (PB03/17); also elsewhere on the board
D24: IC6.14 (D3), IC10.11 (1B7), XC95144XL(RAM).32 (PB03/14); also elsewhere on the board
D25: IC6.13 (D2), IC10.13 (2B1), XC95144XL(RAM).28 (PB03/9); also elsewhere on the board
D26: IC6.9 (D0), IC10.16 (2B3), XC95144XL(RAM).27 (GCLK3/PB03/8); also elsewhere on the board
D27: IC6.10 (D1), IC10.17 (2B4), XC95144XL(RAM).37 (PB05/6); also elsewhere on the board
D28: IC6.32 (D5), IC10.19 (2B5), XC95144XL(RAM).94 (PB04/12); also elsewhere on the board
D29: IC6.35 (D6), IC10.20 (2B6), XC95144XL(RAM).93 (PB04/11); also elsewhere on the board
D30: IC6.36 (D7), IC10.22 (2B7), XC95144XL(RAM).92 (PB04/9); also elsewhere on the board
D31: IC6.31 (D4), IC10.23 (2B8), XC95144XL(RAM).95 (PB04/14); also elsewhere on the board
D68K0: IC10.35 (2A2); also elsewhere on the board
D68K1: IC10.37 (1A8); also elsewhere on the board
D68K2: IC10.40 (1A6); also elsewhere on the board
D68K3: IC10.43 (1A4); also elsewhere on the board
D68K4: IC10.44 (1A3); also elsewhere on the board
D68K5: IC10.46 (1A2); also elsewhere on the board
D68K6: IC10.47 (1A1); also elsewhere on the board
D68K7: IC10.41 (1A5); also elsewhere on the board
D68K8: IC10.38 (1A7); also elsewhere on the board
D68K9: IC10.36 (2A1); also elsewhere on the board
D68K10: IC10.33 (2A3); also elsewhere on the board
D68K11: IC10.32 (2A4); also elsewhere on the board
D68K12: IC10.30 (2A5); also elsewhere on the board
D68K13: IC10.29 (2A6); also elsewhere on the board
D68K14: IC10.27 (2A7); also elsewhere on the board
D68K15: IC10.26 (2A8); also elsewhere on the board
DS20: XC9572XL(BUS).19 (PB01/15), XC95144XL(RAM).8 (PB02/14); also elsewhere on the board
DSACK1: XC9572XL(BUS).4 (PB02/12); also elsewhere on the board
DTACK: XC9572XL(BUS).10 (PB01/6), XC95144XL(RAM).58 (PB07/12); also elsewhere on the board
E: XC9572XL(BUS).24 (PB03/5); also elsewhere on the board
FC0: XC9572XL(BUS).40 (PB03/12); also elsewhere on the board
FC1: XC9572XL(BUS).33 (PB03/11); also elsewhere on the board
FC2: XC9572XL(BUS).31 (PB03/3); also elsewhere on the board
GND: C1.2, C2.2, C7.2, C12.2, C19.2, C20.2, C21.2, C22.2, C23.2, C24.2, C25.2, C26.2, C27.2, C28.2, C29.2, C30.2, IC3.1 (ADJ), IC5.3 (GND), IC6.12 (GND), IC6.34 (GND), IC7.12 (GND), IC7.34 (GND), IC8.12 (GND), IC8.34 (GND), IC9.12 (GND), IC9.34 (GND), IC10.4 (GND), IC10.10 (GND), IC10.15 (GND), IC10.21 (GND), IC10.28 (GND), IC10.34 (GND), IC10.39 (GND), IC10.45 (GND), JTAG.5, OSCCPU.2 (GND), PWR1.1, SPIPORT.3, SPIPORT.4, U1.4 (GND), XC9572XL(BUS).14 (GND), XC9572XL(BUS).21 (GND), XC9572XL(BUS).41 (GND), XC9572XL(BUS).54 (GND), XC95144XL(RAM).21 (GND), XC95144XL(RAM).31 (GND), XC95144XL(RAM).44 (GND), XC95144XL(RAM).62 (GND), XC95144XL(RAM).69 (GND), XC95144XL(RAM).75 (GND), XC95144XL(RAM).84 (GND), XC95144XL(RAM).100 (GND); also elsewhere on the board
HOLD: U1.7 (HOLD), XC95144XL(RAM).56 (PB07/11)
IDECS0: XC9572XL(BUS).62 (PB02/6); also elsewhere on the board
IDECS1: XC9572XL(BUS).61 (PB02/5); also elsewhere on the board
IDEINT: XC95144XL(RAM).49 (PB05/17); also elsewhere on the board
IDEWAIT: XC9572XL(BUS).63 (PB02/8), XC95144XL(RAM).46 (PB05/15); also elsewhere on the board
INT2: INT2.1, XC9572XL(BUS).59 (PB02/4), XC95144XL(RAM).42 (PB05/12)
INTCYCLE: XC9572XL(BUS).56 (PB04/15), XC95144XL(RAM).43 (PB05/14)
IOR: XC9572XL(BUS).1 (PB02/10); also elsewhere on the board
IOW: XC9572XL(BUS).2 (PB02/11); also elsewhere on the board
IPL1: XC9572XL(BUS).57 (PB04/17); also elsewhere on the board
IPL2: XC9572XL(BUS).58 (PB02/3); also elsewhere on the board
LDS: XC9572XL(BUS).8 (PB01/2); also elsewhere on the board
R/W: IC10.1 (1DIR), IC10.24 (2DIR), XC9572XL(BUS).9 (PB01/5); also elsewhere on the board
R/W20: IC6.17 (!WE), IC7.17 (!WE), IC8.17 (!WE), IC9.17 (!WE), XC9572XL(BUS).13 (PB01/4), XC95144XL(RAM).4 (PB02/9); also elsewhere on the board
RAMA2: IC6.1 (A0), IC7.1 (A0), IC8.1 (A0), IC9.1 (A0), XC95144XL(RAM).76 (PB06/5)
RAMA3: IC6.2 (A1), IC7.2 (A1), IC8.2 (A1), IC9.2 (A1), XC95144XL(RAM).77 (PB06/6)
RAMCS0: IC9.6 (!CE), XC95144XL(RAM).91 (PB04/8)
RAMCS1: IC8.6 (!CE), XC95144XL(RAM).90 (PB04/6)
RAMCS2: IC7.6 (!CE), XC95144XL(RAM).89 (PB04/5)
RAMCS3: IC6.6 (!CE), XC95144XL(RAM).87 (PB04/2)
RAMOE: IC6.41 (!OE), IC7.41 (!OE), IC8.41 (!OE), IC9.41 (!OE), XC95144XL(RAM).85 (PB06/15)
RESET: XC95144XL(RAM).24 (PB03/5); also elsewhere on the board
SIZ0: XC9572XL(BUS).36 (PB03/15), XC95144XL(RAM).6 (PB02/11); also elsewhere on the board
SIZ1: XC9572XL(BUS).38 (PB03/17), XC95144XL(RAM).3 (PB02/8); also elsewhere on the board
SPARE: XC9572XL(BUS).64 (PB02/9), XC95144XL(RAM).60 (PB07/15)
SPI_CLK: SPIPORT.7, SPIPORT.8, U1.6 (SCK), XC95144XL(RAM).71 (PB08/14)
SPI_CS0: SPIPORT.11, XC95144XL(RAM).73 (PB08/17)
SPI_CS1: SPIPORT.12, XC95144XL(RAM).74 (PB06/2)
SPI_CS2: U1.1 (CS), XC95144XL(RAM).55 (PB07/9)
SPI_INT: SPI_INT.1, XC95144XL(RAM).65 (PB08/6)
SPI_MISO: SPIPORT.9, SPIPORT.10, U1.2 (MISO), XC95144XL(RAM).72 (PB08/15)
SPI_MOSI: SPIPORT.5, SPIPORT.6, U1.5 (MOSI), XC95144XL(RAM).70 (PB08/12)
STERM: XC95144XL(RAM).11 (PB01/2); also elsewhere on the board
TCK: JTAG.4, XC9572XL(BUS).30 (TCK), XC95144XL(RAM).48 (TCK)
TDI: JTAG.2, XC9572XL(BUS).28 (TDI)
TDINT: XC9572XL(BUS).53 (TDO), XC95144XL(RAM).45 (TDI)
TDO: JTAG.3, XC95144XL(RAM).83 (TDO)
TMS: JTAG.1, XC9572XL(BUS).29 (TMS), XC95144XL(RAM).47 (TMS)
UDS: XC9572XL(BUS).7 (PB02/17); also elsewhere on the board
VCC: C2.1, C19.1, IC3.3 (IN), IC5.5 (VCC), IC6.11 (VCC), IC6.33 (VCC), IC6.40 (CE2), IC7.11 (VCC), IC7.33 (VCC), IC7.40 (CE2), IC8.11 (VCC), IC8.33 (VCC), IC8.40 (CE2), IC9.11 (VCC), IC9.33 (VCC), IC9.40 (CE2), IC10.7 (VCC), IC10.18 (VCC), IC10.31 (VCC), IC10.42 (VCC), PWR1.2; also elsewhere on the board
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

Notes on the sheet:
OVR and INT2 are redudant. They are retained for test purposes only.
Do not connect this resistor unless for testing without the RAM CPLD. It bridges D3 and D19 so that data can be read without the code in the RAM CPLD.

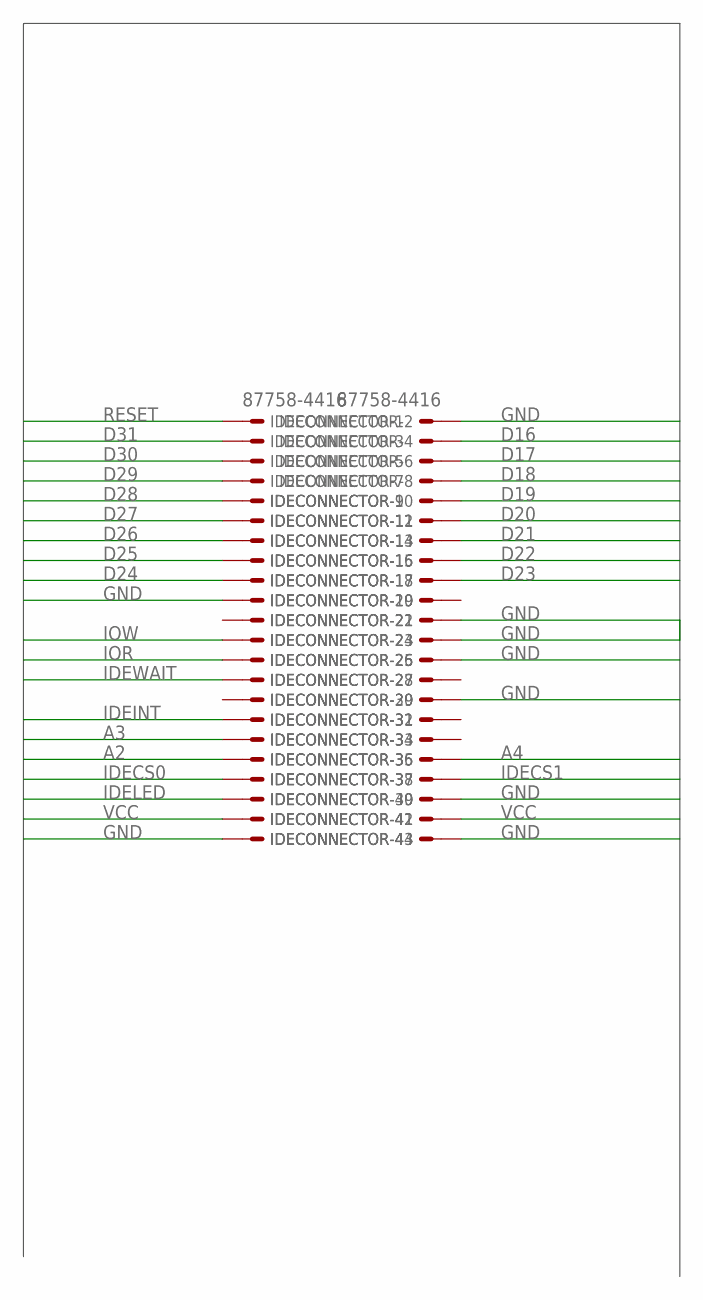
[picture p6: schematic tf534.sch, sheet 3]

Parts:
IDECONNECTOR: 87758-4416

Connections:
A2: IDECONNECTOR.35; also elsewhere on the board
A3: IDECONNECTOR.33; also elsewhere on the board
A4: IDECONNECTOR.36; also elsewhere on the board
D16: IDECONNECTOR.4; also elsewhere on the board
D17: IDECONNECTOR.6; also elsewhere on the board
D18: IDECONNECTOR.8; also elsewhere on the board
D19: IDECONNECTOR.10; also elsewhere on the board
D20: IDECONNECTOR.12; also elsewhere on the board
D21: IDECONNECTOR.14; also elsewhere on the board
D22: IDECONNECTOR.16; also elsewhere on the board
D23: IDECONNECTOR.18; also elsewhere on the board
D24: IDECONNECTOR.17; also elsewhere on the board
D25: IDECONNECTOR.15; also elsewhere on the board
D26: IDECONNECTOR.13; also elsewhere on the board
D27: IDECONNECTOR.11; also elsewhere on the board
D28: IDECONNECTOR.9; also elsewhere on the board
D29: IDECONNECTOR.7; also elsewhere on the board
D30: IDECONNECTOR.5; also elsewhere on the board
D31: IDECONNECTOR.3; also elsewhere on the board
GND: IDECONNECTOR.2, IDECONNECTOR.19, IDECONNECTOR.22, IDECONNECTOR.24, IDECONNECTOR.26, IDECONNECTOR.30, IDECONNECTOR.40, IDECONNECTOR.43, IDECONNECTOR.44; also elsewhere on the board
IDECS0: IDECONNECTOR.37; also elsewhere on the board
IDECS1: IDECONNECTOR.38; also elsewhere on the board
IDEINT: IDECONNECTOR.31; also elsewhere on the board
IDELED: IDECONNECTOR.39
IDEWAIT: IDECONNECTOR.27; also elsewhere on the board
IOR: IDECONNECTOR.25; also elsewhere on the board
IOW: IDECONNECTOR.23; also elsewhere on the board
RESET: IDECONNECTOR.1; also elsewhere on the board
VCC: IDECONNECTOR.41, IDECONNECTOR.42; also elsewhere on the board

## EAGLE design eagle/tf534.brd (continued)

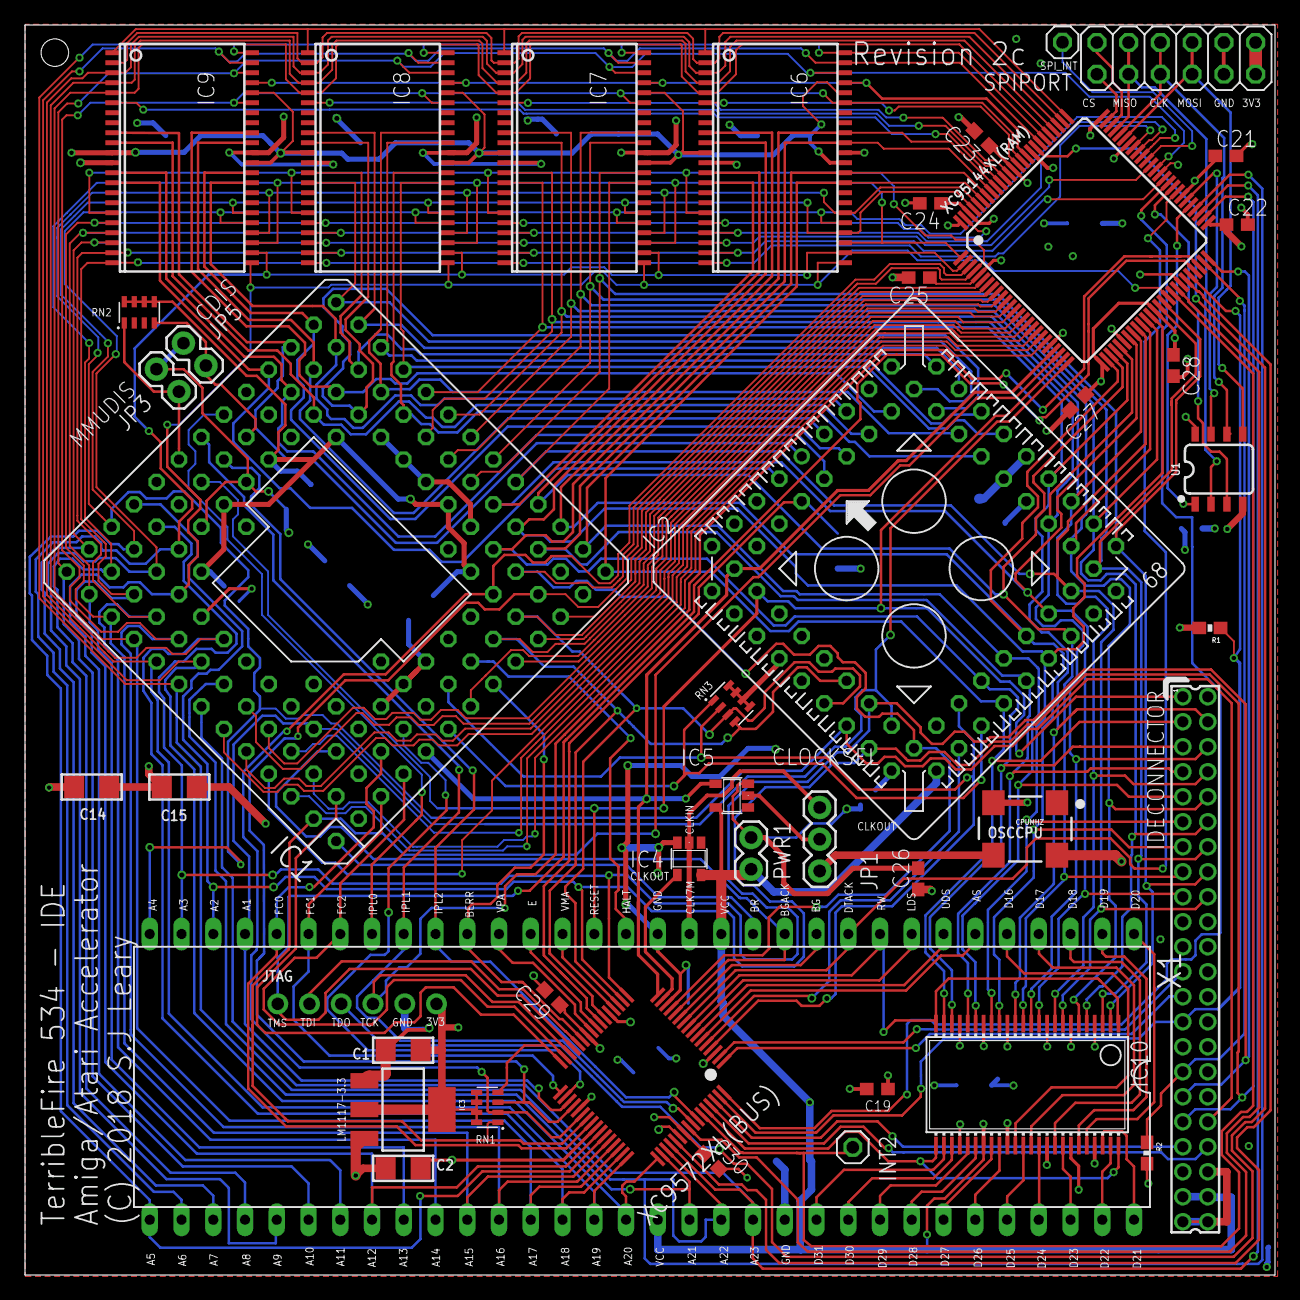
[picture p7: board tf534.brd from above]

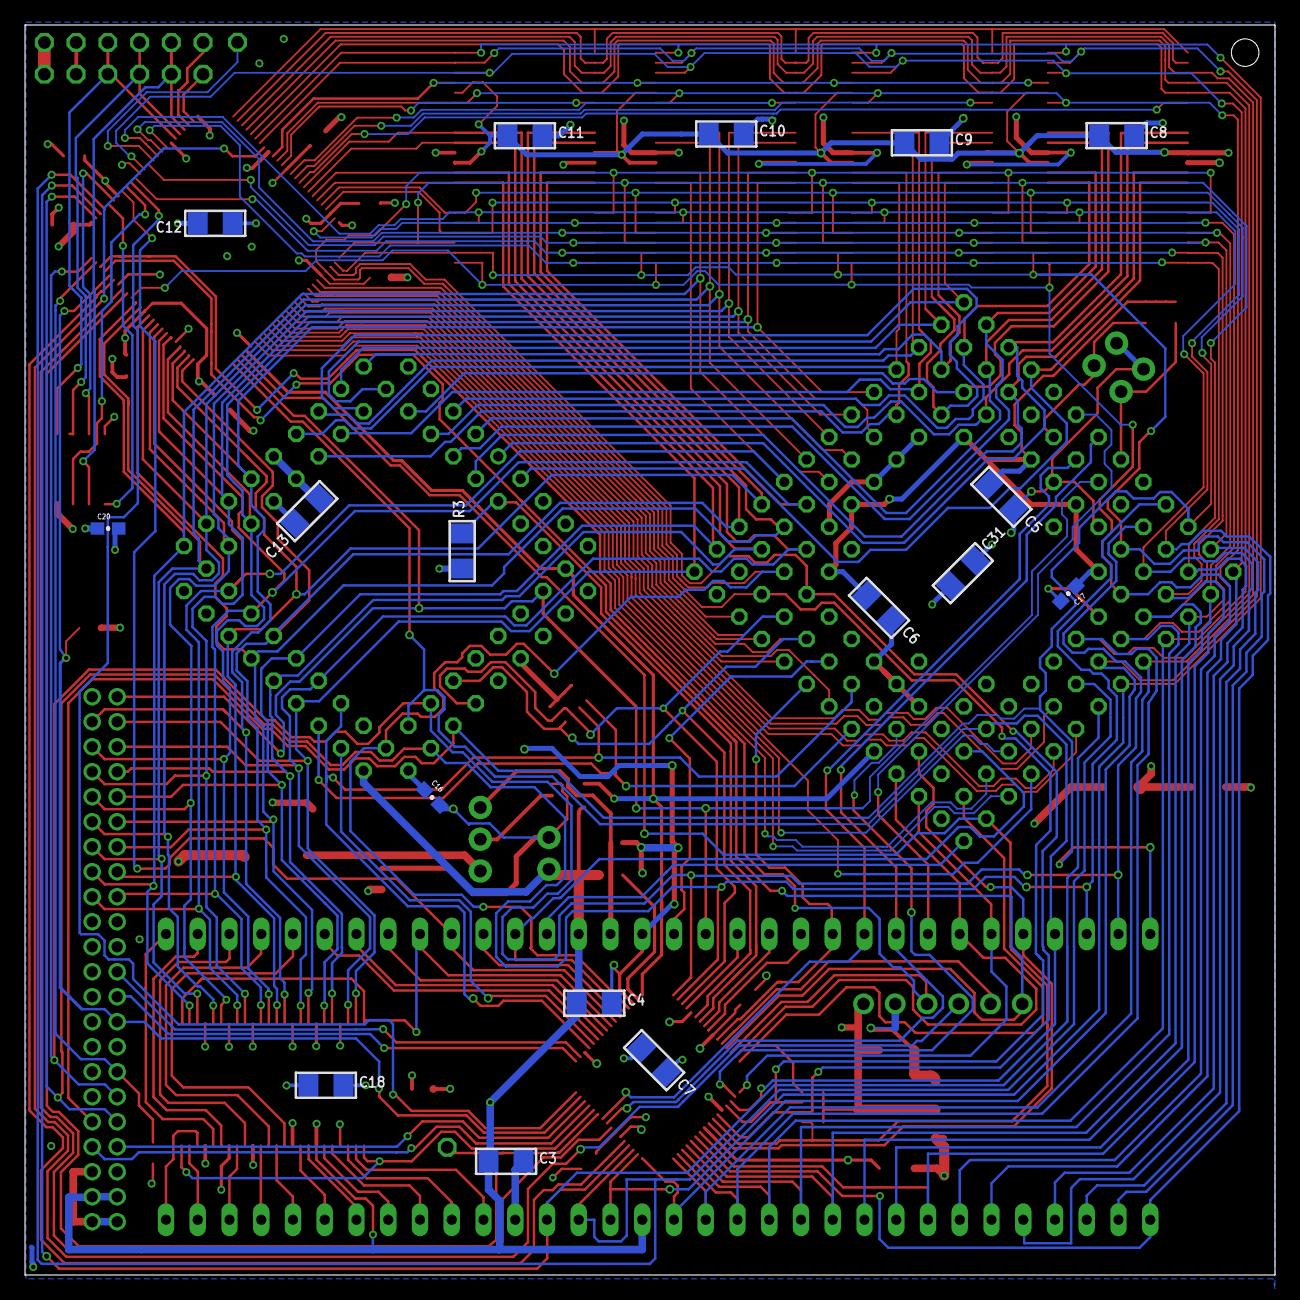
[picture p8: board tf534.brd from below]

Board: 4 copper layers, 100.0 x 100.0 mm, 61 parts (17 on the bottom side), 156 nets.

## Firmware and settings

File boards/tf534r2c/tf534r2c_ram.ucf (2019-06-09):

# Copyright (C) 2016-2019, Stephen J. Leary
# All rights reserved.
# 
# This file is part of  TF534 (Terrible Fire 030 Accelerator).
# 
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

#Clocks
NET "CLKCPU"      LOC="22";
NET "CLKCPU" BUFG=CLK;
NET "CLKCPU" TNM_NET = "CLKCPU"; # gives the net clk a group name as CLKCPU
TIMESPEC "TS_CLKCPU" = PERIOD "CLKCPU" 12 ns ; # add 20 ns PERIOD constraint the
#OFFSET = IN 15 ns VALID 5ns BEFORE "CLKCPU" ; # add  offset in constraint
OFFSET = OUT 5 ns AFTER "CLKCPU" ; # add  offset out constraint

NET "A<0>"       LOC="23";
NET "A<1>"       LOC="25";
NET "A<2>"       LOC="52";
NET "A<3>"       LOC="50";
NET "A<4>"       LOC="96";
NET "A<5>"       LOC="97";
NET "A<6>"       LOC="2";
NET "A<8>"       LOC="1";
NET "A<12>"      LOC="68";
NET "A<13>"      LOC="67";
NET "A<15>"      LOC="99";
NET "A<16>"      LOC="86";
NET "A<17>"      LOC="80";
NET "A<18>"      LOC="79";
NET "A<19>"      LOC="78";
NET "A<20>"      LOC="82";
NET "A<21>"      LOC="81";
NET "A<22>"      LOC="54";
NET "A<23>"      LOC="53";
NET "A<24>"      LOC="16";
NET "A<25>"      LOC="14";
NET "A<26>"      LOC="15";
NET "A<27>"      LOC="13";
NET "A<28>"      LOC="17";
NET "A<29>"      LOC="18";
NET "A<30>"      LOC="19";
NET "A<31>"      LOC="20";
NET "AS20"       LOC="10";
NET "CBACK"      LOC="12";
NET "CBREQ"      LOC="9";
NET "CIIN"       LOC="7";

NET "D<0>"       LOC="29";
NET "D<1>"       LOC="30";
NET "D<2>"       LOC="33";
NET "D<3>"       LOC="35";
NET "D<4>"       LOC="36";
NET "D<5>"       LOC="39";
NET "D<6>"       LOC="40";
NET "D<7>"       LOC="34";
NET "D<8>"       LOC="32";
NET "D<9>"       LOC="28";
NET "D<10>"      LOC="27";
NET "D<11>"      LOC="37";
NET "D<12>"      LOC="94";
NET "D<13>"      LOC="93";
NET "D<14>"      LOC="92";
NET "D<15>"      LOC="95";

NET "DS20"       LOC="8";
NET "DTACK"      LOC="58";
NET "HOLD"       LOC="56";
NET "IDEINT"     LOC="49";
NET "IDEWAIT"    LOC="46";
NET "INT2"       LOC="42";
NET "INTCYCLE"   LOC="43";
NET "RW20"       LOC="4";
NET "RAMA<2>"    LOC="76";
NET "RAMA<3>"    LOC="77";
NET "RAMCS<0>"   LOC="91";
NET "RAMCS<1>"   LOC="90";
NET "RAMCS<2>"   LOC="89";
NET "RAMCS<3>"   LOC="87";
NET "RAMOE"      LOC="85";
NET "RESET"      LOC="24";
#NET "ROMEN<0>"  LOC="66";
#NET "ROMEN<1>"  LOC="64";
NET "SIZ<0>"     LOC="6";
NET "SIZ<1>"     LOC="3";
NET "SLOWCYCLE"  LOC="60";
NET "SPI_CLK"    LOC="71";
NET "SPI_CS<0>"  LOC="73";
NET "SPI_CS<1>"  LOC="74";
NET "SPI_WCS"    LOC="55";
#NET "SPI_INT"   LOC="65";
NET "SPI_MISO"   LOC="72";
NET "SPI_MOSI"   LOC="70";
NET "STERM"      LOC="11";
NET "WRITEPROT"  LOC="59";

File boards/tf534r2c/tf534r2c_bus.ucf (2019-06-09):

# Copyright (C) 2016-2019, Stephen J. Leary
# All rights reserved.
# 
# This file is part of  TF534 (Terrible Fire 030 Accelerator).
# 
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

#Clocks
NET "CLKCPU"		LOC="16";
NET "CLKCPU" BUFG=CLK;
NET "CLKCPU" TNM_NET = "CLKCPU"; # gives the net clk a group name as CLKCPU
TIMESPEC "TS_CLKCPU" = PERIOD "CLKCPU" 20 ns ; # add 20 ns PERIOD constraint the
OFFSET = IN 15 ns VALID 10 ns BEFORE "CLKCPU" ; # add  offset in constraint
OFFSET = OUT 15 ns AFTER "CLKCPU" ; # add  offset out constraint
NET "CLK7M"		LOC="15";
NET "CLK7M" BUFG=CLK;
NET "CLK7M" TNM_NET = "CLK7M"; # gives the net clk a group name as CLK7M
TIMESPEC "TS_CLK7M" = PERIOD "CLK7M" 139 ns ; # add 139 ns PERIOD constraint the
#Created by Constraints Editor (xc9572xl-vq64-10) - 2018/04/08
OFFSET = IN 20 ns VALID 10 ns BEFORE "CLK7M"; # add  offset in constraint
OFFSET = OUT 15 ns AFTER "CLK7M" ; # add  offset out constraint
NET "A<0>"      LOC="39";
NET "A<1>"      LOC="35";
NET "A<2>"      LOC="18";
NET "A<3>"      LOC="17";
NET "A<5>"      LOC="43";
NET "A<12>"      LOC="42";
NET "A<15>"      LOC="44";
NET "A<16>"      LOC="45";
NET "A<17>"      LOC="46";
NET "A<18>"      LOC="47";
NET "A<19>"      LOC="48";
NET "A<20>"      LOC="49";
NET "A<21>"      LOC="50";
NET "A<22>"      LOC="51";
NET "A<23>"      LOC="52";
NET "AS"      LOC="6";
NET "AS20"      LOC="22";
NET "AVEC"      LOC="34";
NET "BERR"      LOC="27";
NET "BG"      LOC="11";
NET "BG20"      LOC="32";
NET "BGACK"      LOC="12";
NET "BUSEN"      LOC="60";
NET "CPCS"      LOC="5";
NET "CPSENSE"      LOC="23";
NET "DS20"      LOC="19";
NET "DSACK1"      LOC="4";
NET "DTACK"      LOC="10";
NET "E"      LOC="24";
NET "FC<0>"      LOC="40";
NET "FC<1>"      LOC="33";
NET "FC<2>"      LOC="31";
NET "IDECS<0>"      LOC="62";
NET "IDECS<1>"      LOC="61";
NET "IDEWAIT"      LOC="63";
NET "INT2"      LOC="59";
NET "INTCYCLE"      LOC="56";
NET "IOR"      LOC="1";
NET "IOW"      LOC="2";
NET "IPL<1>"      LOC="57";
NET "IPL<2>"      LOC="58";
NET "LDS"      LOC="8";
NET "RW"      LOC="9";
NET "RW20"      LOC="13";
NET "SIZ<0>"      LOC="36";
NET "SIZ<1>"      LOC="38";
NET "SLOWCYCLE"      LOC="64";
NET "UDS"      LOC="7";
NET "VMA"      LOC="20";
NET "VPA"      LOC="25";

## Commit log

2019-03-28 added the open board view file
    [tf534_obv.brd]
2019-06-09 Adding all the sources for the TF534 and TF53x firmwares
    [tf534.brd, tf534.sch]
2019-09-25 Added Atari support to TF534r2c
    - Exposed onboard ram as TT-RAM
    - IDE interface mapped for Atari
    - IDE interrupt wired to INT2 pin (connect to ASCI10 for IDE support under Atari TOS)
2019-10-22 Atari TF530r3
    TF530r3:
    - Makefile fixes to allow building this board for Atari
    - Expose onboard ram as 2MB TT-RAM at 0x01000000

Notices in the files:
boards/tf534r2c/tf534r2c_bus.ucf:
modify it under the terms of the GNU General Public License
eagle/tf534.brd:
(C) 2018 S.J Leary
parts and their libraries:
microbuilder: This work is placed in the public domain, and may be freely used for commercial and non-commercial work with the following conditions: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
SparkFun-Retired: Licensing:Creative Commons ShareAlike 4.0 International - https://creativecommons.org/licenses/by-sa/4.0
